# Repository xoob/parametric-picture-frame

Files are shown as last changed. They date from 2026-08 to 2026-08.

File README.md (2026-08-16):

# Parametric Picture Frame

We have a 130 × 90 cm painting on stretched canvas and no frame for it. A real
frame in that size costs a fortune, so I'm printing one — on an A1 Mini with a
180 mm bed. This generator does the math for that: it splits the frame into 38
pieces with press-fit dovetails (no glue), plus 18 clips that hold the canvas
from behind.

Everything is one OpenSCAD project. Pick one of three *Querschnitt* (cross-section) styles, set
your canvas size, and the ornament is generated mathematically so that every
seam lands in a valley of the pattern. The finished frame comes out around
145 × 105 cm with an 85 mm moulding. The painting keeps hanging on its own two
wall screws — the frame just clips onto the stretcher and adds the drama.

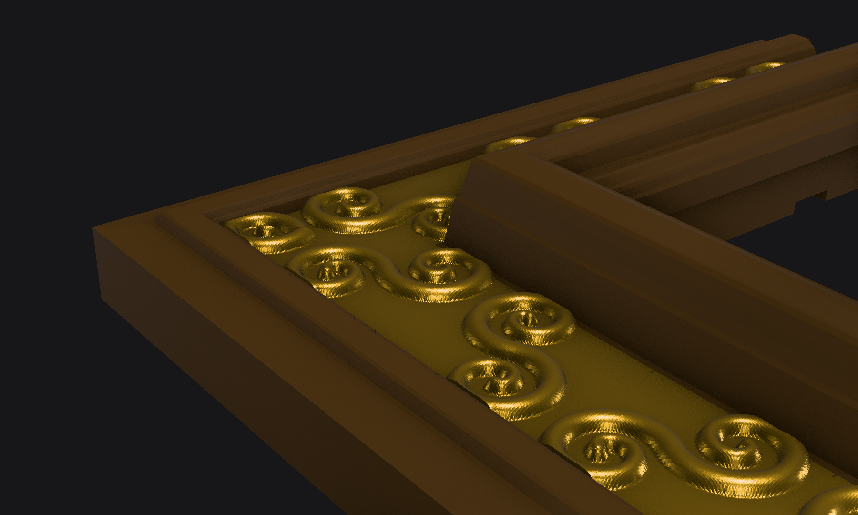
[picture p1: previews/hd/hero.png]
Frame corner, F3D render


| | |
|---|---|
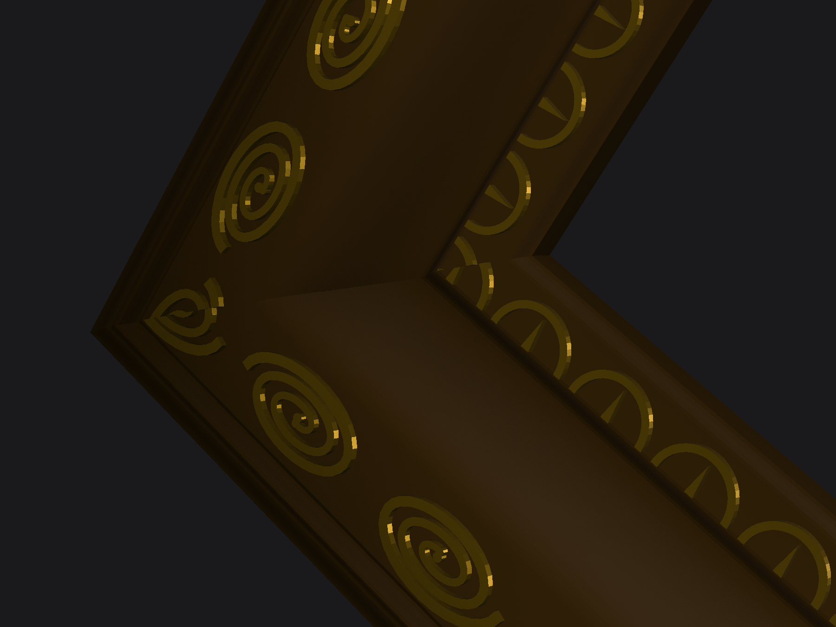
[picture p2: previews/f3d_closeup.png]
Corner close-up, F3D render
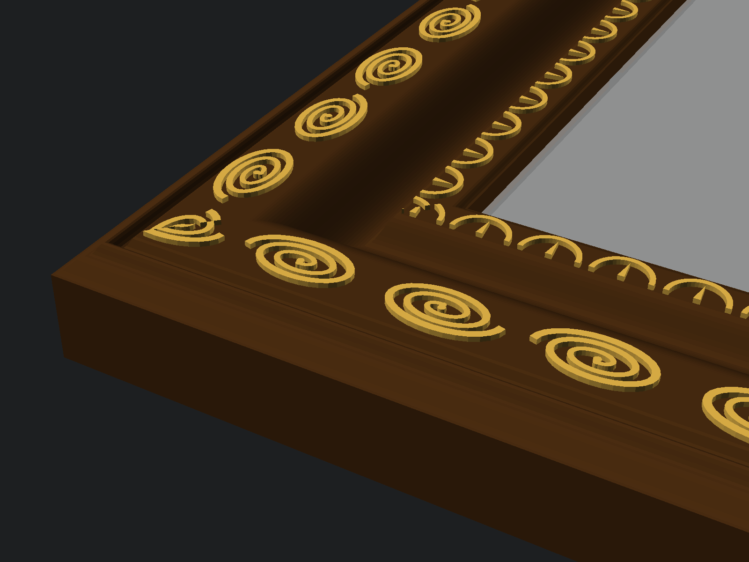
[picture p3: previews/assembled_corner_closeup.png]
Corner detail, OpenSCAD preview
|  |  |
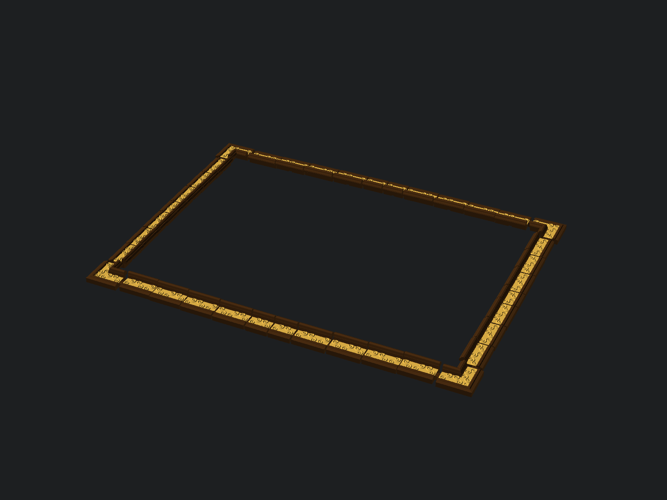
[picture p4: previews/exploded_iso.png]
Exploded segmentation view
|  | View [`parametric-picture-frame.glb`](parametric-picture-frame.glb) interactively at [f3d.app/viewer](https://f3d.app/viewer) |

## Files

- `parametric-picture-frame.scad` — all parameters (OpenSCAD Customizer compatible) + render modes
- `lib/profiles.scad` — the 3 cross-section styles: `ogee`, `reverse_ogee`, `ripple`
- `lib/ornament.scad` — mathematically generated relief (running scroll + scallop bands)
- `lib/segmentation.scad` — bed-aware cut planning + dovetail joints
- `lib/clips.scad` — canvas retainer clips
- `export-all.sh` — exports every part STL into `stl/`

## Bambu Studio export

The project 3mf is built by the local `openscad-3mf` skill (Claude Code), not
by a script in this repo:

```
./export-all.sh
read -r NH NV <<< "$(grep -o 'COUNTS [0-9]* [0-9]*' /tmp/frame_bom.echo | awk '{print $2, $3}')"
parts=(corner_BL B{1..$NH} corner_BR R{1..$NV} corner_TR T{$NH..1} corner_TL L{$NV..1} clips)
python3 ~/.claude/skills/openscad-3mf/scripts/build-3mf.py stl/${^parts}.stl \
  --out parametric-picture-frame.3mf --overrides bambu/overrides.json
```

Result: 39 objects on 23 A1 Mini plates in assembly order (plate previews
render on first slice), presets set (A1 mini 0.6 nozzle, PLA Matte, 0.42mm
Extra Draft) and the overrides from `bambu/overrides.json` — lightning infill,
10%, 2 walls, Arachne, auto supports — bundled as orange modified fields.
Nothing is sliced: open in Bambu Studio, check, slice, print plate by plate.

The 3mf is a Bambu Studio project file — plates and settings are Bambu-specific
metadata. Other slicers: use the STLs from `./export-all.sh` instead.

## Render modes (`render_mode`)

| mode | output |
|---|---|
| `assembled` | whole frame + ghost canvas (sanity view) |
| `exploded` | all parts pulled apart, tenons visible |
| `part` | one printable piece: `part_kind` (`straight`/`corner`) + `part_leg` + `part_index` |
| `fit_test` | small dovetail coupon pair — **print this first** |
| `clips` | plate with all retainer clips |
| `bom` | no geometry; echoes part list, sizes, screw count |

Corners are named by the leg at whose CCW start they sit: `bottom`→BL,
`right`→BR, `top`→TR, `left`→TL. Every part has its ID engraved in the back.

## Print settings (tested target)

- Bambu A1 Mini, Cool Super Tack plate, Matte Black PLA, 0.6 mm nozzle
- Orientation: decorative face UP (exports already lie this way)
- Supports ON (auto): the lip underside floats over the rabbet void — supports
  generate only there. The 3mf overrides enable this
- 2 walls, **lightning infill** — the frame is decorative, not structural
- The dovetail pocket roof is a small internal bridge; default bridge settings are fine

## Workflow

1. **Print `fit_test.stl`** (both coupons). Press together face-down like the
   real parts. Too tight → raise `dovetail_clearance` (steps of 0.04);
   too loose → lower it or raise `dovetail_taper`.
2. **Measure the coupon** (nominal 28 mm blocks). If it printed short, set the
   shrink factor, e.g. 0.3% short → `./export-all.sh 1.003`. The factor scales
   every part identically, so joints stay matched. On a 1300 mm span 0.3%
   is ~4 mm — this matters; `fit_clearance = 4` also budgets for it.
3. **Export everything**: `./export-all.sh [shrink]` → `stl/`.
4. **Print** 38 parts + `clips.stl` (18 clips, ~1 part per A1 Mini plate for
   the big segments).
5. **Assemble face-down on a flat surface**: corners first, then straights,
   dropping each tenon into its neighbor's pocket and pressing until seated.
   IDs run CCW: BL → B1…B7 → BR → R1…R5 → TR → T7…T1 → TL → L5…L1.
   Optional: a drop of CA glue in each pocket for permanence.
6. **Mount**: lay the frame face-down, drop the canvas into the pocket
   (it sits fully recessed), screw the 14 clips into the pilot-hole pockets
   (M3 × 8 self-tapping), noses over the stretcher bars. Rehang the painting
   on its existing two wall screws — the frame rides on the stretcher and the
   flat back sits flush against the wall.

## Key parameters

- `painting_width/height/thickness` — canvas size (default 1300 × 900 × 20 mm)
- `fit_clearance` — slack per side (default 4 mm; hidden by the lip)
- `lip_overlap` — how far the front lip overlaps the painting face (default 10 mm)
- `frame_scale` — moulding size, proportional to the painting diagonal
- `profile_style` — `ogee` (trade name "Swan": roll + sunken gold channel),
  `reverse_ogee` ("Reverse Scoop": crown rising away from the art), `ripple`
  ("Stepped": ribbed *Wellenleiste* (wave moulding))
- `ornament_*` — relief on/off, height, repeat period (seams always land in valleys)
- `printer` — `A1 Mini`, `A1`, `P1 X1`, `H2D` bed presets
- `dovetail_clearance/taper`, `shrinkage_compensation` — joint fit tuning
- `hanger_keyholes` — opt-in keyholes in the top corners for direct wall mounting

Multi-color gold-on-black like the reference: in Bambu Studio, use
*Color Painting → Height Range* to paint everything above the band surfaces
(top ~1.6 mm of the relief) gold.

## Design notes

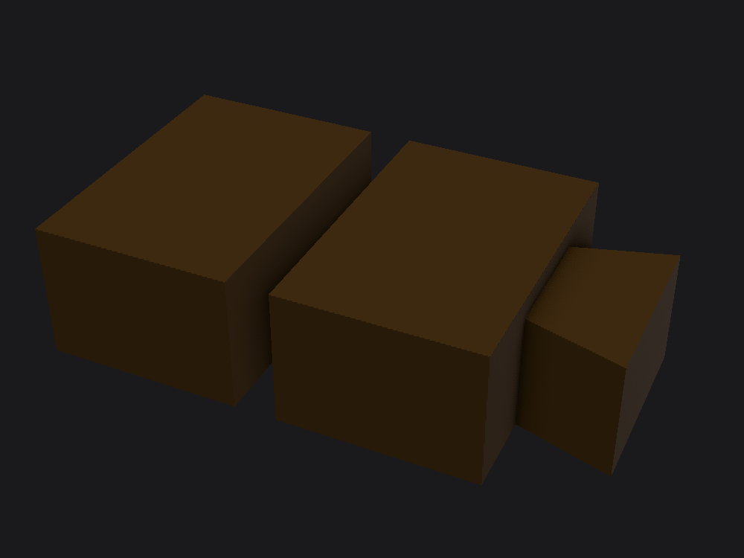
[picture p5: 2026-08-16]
previews/hd/fit_iso.png

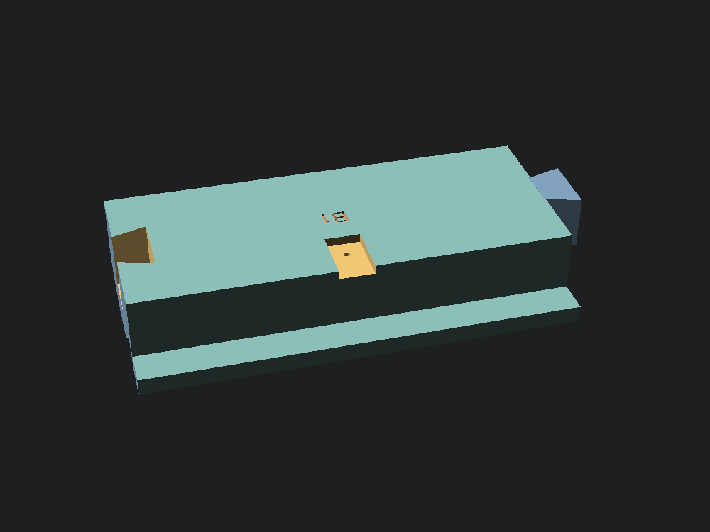
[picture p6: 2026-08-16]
previews/part_b1_back.png

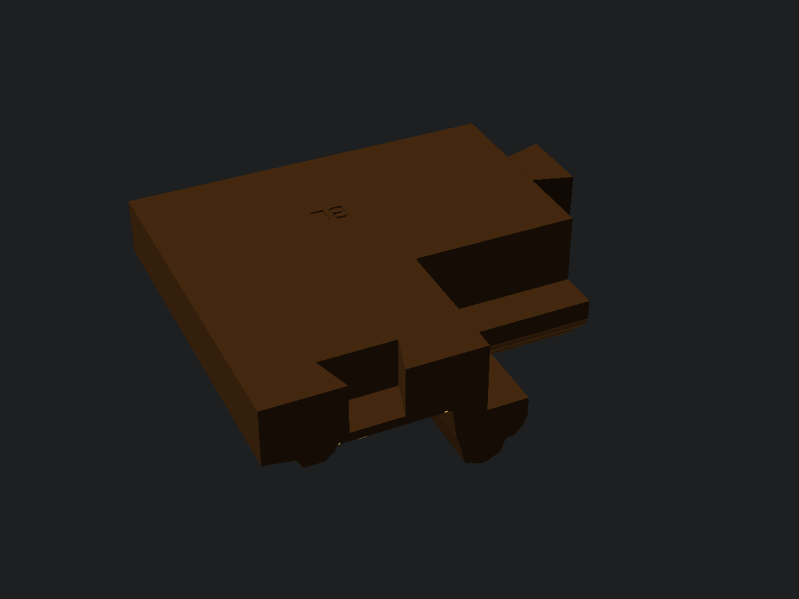
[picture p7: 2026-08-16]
previews/corner_bl_back.png

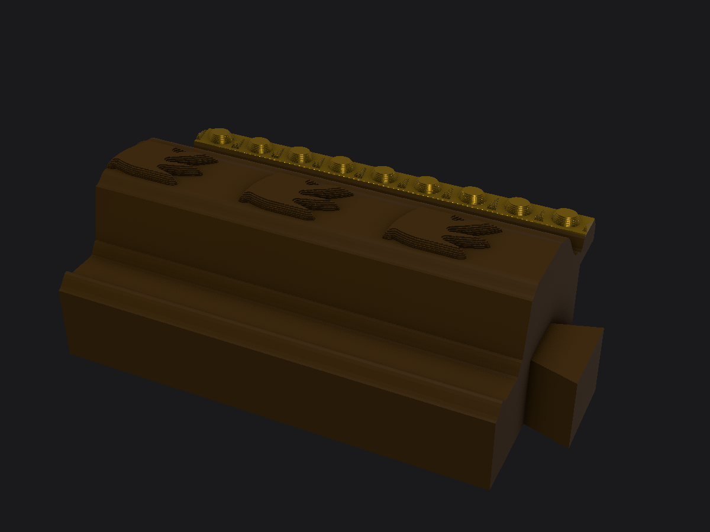
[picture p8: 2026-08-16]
previews/hd/style_revogee.png

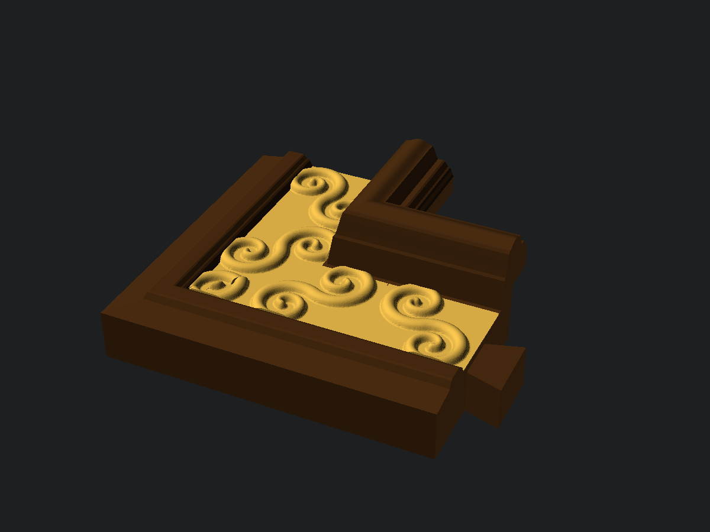
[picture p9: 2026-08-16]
previews/corner_bl_iso.png

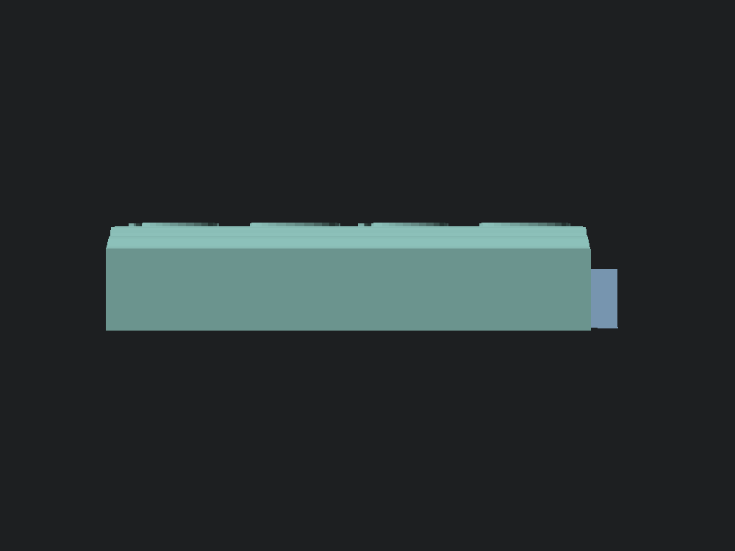
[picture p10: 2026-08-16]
previews/part_b2_front.png

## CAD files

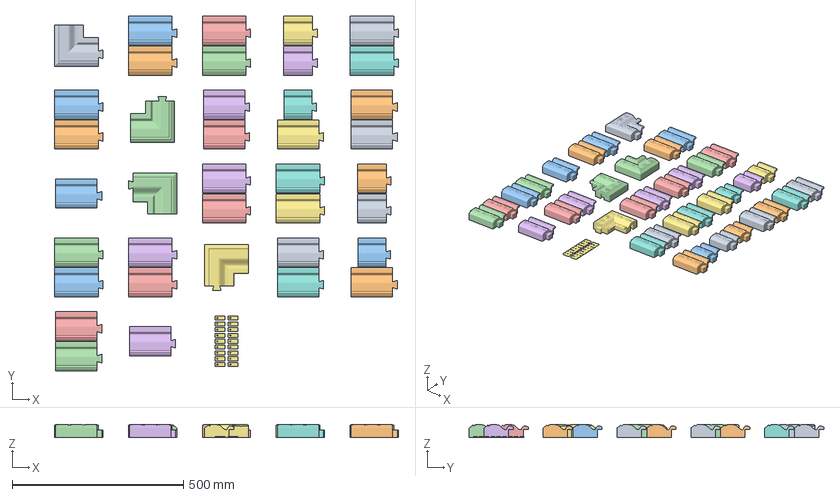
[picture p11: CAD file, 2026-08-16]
parametric-picture-frame.3mf
1005.7 x 1036.8 x 38.9 mm
corner_BL.stl
B1.stl
B2.stl
B3.stl
B4.stl
B5.stl
B6.stl
B7.stl
B8.stl
B9.stl
B10.stl
corner_BR.stl
R1.stl
R2.stl
R3.stl
R4.stl
R5.stl
R6.stl
R7.stl
corner_TR.stl
T10.stl
T9.stl
T8.stl
T7.stl
T6.stl
T5.stl
T4.stl
T3.stl
T2.stl
T1.stl
corner_TL.stl
L7.stl
L6.stl
L5.stl
L4.stl
L3.stl
L2.stl
L1.stl
clips.stl

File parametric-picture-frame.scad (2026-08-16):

// Parametric ornate picture frame, segmented for small-bed 3D printing.
//
// The frame is generated around a frameless canvas painting, split into
// one-piece L corners plus straight segments that each fit the selected
// printer bed, joined by glueless press-fit dovetails. The canvas sits fully
// recessed; printed clips hold it and carry the frame off the stretcher.
//
// Print orientation (all parts): decorative face UP, back plane on the bed.
// Supports required: the lip underside floats over the rabbet void.
// Suggested slicing: 0.6 mm nozzle, 2 walls, lightning infill, auto supports.
//
// Workflow: print fit_test first, tune dovetail_clearance/shrinkage_compensation,
// then export all parts with export-all.sh.

/* [Painting] */
// Painting width (mm)
painting_width = 1300;        // [100:5:3000]
// Painting height (mm)
painting_height = 900;        // [100:5:3000]
// Painting/stretcher thickness (mm)
painting_thickness = 20;      // [5:1:60]
// Slack per side around the canvas (mm) — covers PLA shrinkage over long spans
fit_clearance = 4;            // [0:0.5:10]
// Front lip overlapping the painting face (mm)
lip_overlap = 10;             // [4:1:30]

/* [Frame look] */
// Cross-section style
profile_style = "ogee";       // [ogee, reverse_ogee, ripple]
// Moulding scale, proportional to painting size (1.0 = 5.4% of diagonal)
frame_scale = 1.0;            // [0.5:0.05:2.0]
// Generate relief ornament on the bands
ornament_enable = true;
// Ornament relief height (mm)
ornament_depth = 2.6;         // [1.0:0.2:4]
// Target ornament repeat period (mm)
ornament_period_target = 42;  // [24:2:80]
// Preview color of the frame body (previews only, not exported)
body_color = "#43280f";
// Preview color of the ornament relief (previews only, not exported)
ornament_color = "#d4a843";

/* [Printer / segmentation] */
// Bed preset
printer = "A1 Mini";          // [A1 Mini, A1, P1 X1, H2D]
// Keep-out margin per bed side (mm)
bed_margin = 2.5;             // [0:0.5:10]
// Dovetail clearance per side (mm) — press fit; tune with fit_test
dovetail_clearance = 0.08;    // [0:0.02:0.5]
// Dovetail flank taper (deg) — wedge-locks the glueless joint
dovetail_taper = 0.4;         // [0:0.1:2]
// Uniform XY scale on exported parts (1.003 = +0.3% shrink compensation)
shrinkage_compensation = 1.0; // [0.99:0.001:1.02]

/* [Output] */
render_mode = "assembled";    // [assembled, exploded, part, profile, hero, fit_test, clips, bom]
// Which kind of part to export (render_mode=part)
part_kind = "straight";       // [straight, corner]
// Leg; a corner is the one at this leg's CCW start: bottom=BL, right=BR, top=TR, left=TL
part_leg = "bottom";          // [bottom, right, top, left]
// Straight segment number along the leg (CCW direction)
part_index = 1;               // [1:1:12]
// Gap between parts in exploded view (mm)
explode_gap = 30;             // [0:5:100]
// Restrict assembled output to one material group (for colored GLB/3MF export)
export_group = "all";         // [all, body, ornament]

/* [Mounting] */
// Canvas recess behind the back plane (mm); also the rabbet depth minus canvas
rabbet_extra = 4;             // [2:1:10]
// Keyhole wall hangers in the two top corners (normally the frame hangs on the stretcher)
hanger_keyholes = false;

/* [Hidden] */
$fa = 5;
$fs = 0.5;          // coarsest acceptable for a 0.4 mm nozzle; we print 0.6
curve_step = 0.8;   // profile sampling step (mm)
orn_embed = 0.6;    // how deep ornament sinks into the band surface (mm)
label_depth = 0.8;  // part ID engraving depth in the back (mm)

// ---- derived dimensions (all mm) ----
sight_w = painting_width - 2 * lip_overlap;
sight_h = painting_height - 2 * lip_overlap;
lip_w = lip_overlap + fit_clearance;
face_w = 0.054 * norm([painting_width, painting_height]) * frame_scale;
rabbet_depth = painting_thickness + rabbet_extra;
profile_h = max(prof_h_ratio(profile_style) * face_w, rabbet_depth + 12);
frame_ow = sight_w + 2 * face_w;
frame_oh = sight_h + 2 * face_w;

bed = printer == "A1 Mini" ? [180, 180] :
      printer == "A1"      ? [256, 256] :
      printer == "P1 X1"   ? [256, 256] :
      printer == "H2D"     ? [350, 320] :
      assert(false, str("unknown printer: ", printer)) [0, 0];
usable = min(bed[0], bed[1]) - 2 * bed_margin;

include <lib/profiles.scad>
include <lib/segmentation.scad>
include <lib/ornament.scad>
include <lib/clips.scad>

PC = prof_curve(profile_style);

// dovetail geometry, centered on the solid body between rabbet wall and outer edge
dt_yc = (face_w - lip_w) / 2;
dt_wn = 0.20 * face_w;
dt_wh = 0.30 * face_w;
dt_dl = 0.16 * face_w;
dt_h = min(rabbet_depth - 2,
           profile_h * prof_min_z(PC,
             (face_w - (dt_yc + dt_wh / 2 + 2)) / face_w,
             (face_w - (dt_yc - dt_wh / 2 - 2)) / face_w) - 2.9);
dt_taper_off = tan(dovetail_taper) * dt_h;

// segmentation grids (horizontal legs: bottom/top; vertical legs: left/right).
// Every part carries its male tenon dt_dl beyond the cut — the FULL part
// including the tenon must fit the bed, so the segment budget shrinks by dt_dl.
usable_part = usable - dt_dl;
p_h = grid_period(frame_ow, ornament_period_target);
p_v = grid_period(frame_oh, ornament_period_target);
cuts_h = cuts_for(frame_ow, p_h, usable_part);
cuts_v = cuts_for(frame_oh, p_v, usable_part);
nseg_h = len(cuts_h) - 1;
nseg_v = len(cuts_v) - 1;
arm_h = cuts_h[0];
arm_v = cuts_v[0];

// ---- sanity checks ----
assert(face_w <= usable, "moulding wider than the printer bed — reduce frame_scale");
assert(profile_h * prof_min_z(PC, 0, lip_w / face_w) >= rabbet_depth + 5,
       "lip too thin over the rabbet — raise frame_scale or lower rabbet_extra");
assert(dt_h >= 8, "dovetail too shallow — raise frame_scale");
// bed-fit including the protruding tenon (a part's true bounding box)
assert(max([for (i = [1:nseg_h]) cuts_h[i] - cuts_h[i - 1]]) + dt_dl <= usable,
       "segment + tenon exceeds bed");
assert(max([for (i = [1:nseg_v]) cuts_v[i] - cuts_v[i - 1]]) + dt_dl <= usable,
       "segment + tenon exceeds bed");
assert(max(arm_h, arm_v) + dt_dl <= usable, "corner + tenon exceeds bed");
assert(orn_min_w >= 2.0, "ornament features below printable width");
assert(part_index >= 1, "part_index starts at 1");

// ---- leg helpers ----
LEGS = ["b", "r", "t", "l"];
function prev_leg(leg) = leg == "b" ? "l" : leg == "r" ? "b" : leg == "t" ? "r" : "t";
function leg_letter(leg) = leg == "b" ? "B" : leg == "r" ? "R" : leg == "t" ? "T" : "L";
function corner_code(leg) = leg == "b" ? "BL" : leg == "r" ? "BR" : leg == "t" ? "TR" : "TL";
function leg_horiz(leg) = leg == "b" || leg == "t";
function legL(leg) = leg_horiz(leg) ? frame_ow : frame_oh;
function leg_p(leg) = leg_horiz(leg) ? p_h : p_v;
function leg_cuts(leg) = leg_horiz(leg) ? cuts_h : cuts_v;
function leg_nseg(leg) = leg_horiz(leg) ? nseg_h : nseg_v;
// clips sit at the centers of the odd straight segments (1, 3, 5, ...)
function clip_xs(leg) = let(cs = leg_cuts(leg))
  [for (i = [0:2:len(cs) - 2]) (cs[i] + cs[i + 1]) / 2];
n_clips = 2 * len(clip_xs("b")) + 2 * len(clip_xs("r"));

// leg-local -> global point mapping (matches leg_xform)
function leg_pt(leg, x, y) =
  leg == "b" ? [-frame_ow / 2 + x, -frame_oh / 2 + y] :
  leg == "r" ? [frame_ow / 2 - y, -frame_oh / 2 + x] :
  leg == "t" ? [frame_ow / 2 - x, frame_oh / 2 - y] :
               [-frame_ow / 2 + y, frame_oh / 2 - x];

function corner_center(leg) =
  leg == "b" ? [-frame_ow / 2 + arm_h / 2, -frame_oh / 2 + arm_v / 2] :
  leg == "r" ? [frame_ow / 2 - arm_h / 2, -frame_oh / 2 + arm_v / 2] :
  leg == "t" ? [frame_ow / 2 - arm_h / 2, frame_oh / 2 - arm_v / 2] :
               [-frame_ow / 2 + arm_h / 2, frame_oh / 2 - arm_v / 2];

function _unit2(v) = norm(v) < 1e-9 ? [1, 0] : v / norm(v);

module leg_xform(leg) {
  if (leg == "b") translate([-frame_ow / 2, -frame_oh / 2, 0]) children();
  else if (leg == "r") translate([frame_ow / 2, -frame_oh / 2, 0]) rotate([0, 0, 90]) children();
  else if (leg == "t") translate([frame_ow / 2, frame_oh / 2, 0]) rotate([0, 0, 180]) children();
  else translate([-frame_ow / 2, frame_oh / 2, 0]) rotate([0, 0, 270]) children();
}

// ---- leg geometry (leg-local: runs +X over [0,L], outer edge at y=0) ----
module leg_body(L) {
  rotate([90, 0, 90])
    linear_extrude(L, convexity = 10)
      polygon(leg_xsec_pts(PC, face_w, profile_h, lip_w, rabbet_depth, curve_step));
}

function wedge_pts(L) = [[0, 0], [L, 0], [L - face_w, face_w], [face_w, face_w]];

module leg_wedge(L) {
  linear_extrude(profile_h + ornament_depth + 2, convexity = 10)
    polygon(wedge_pts(L));
}
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

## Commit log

2026-08-16 Parametric segmented picture frame for small-bed 3D printing
    Ornate OpenSCAD frame generated around a frameless canvas painting:
    3 profile styles, mathematically generated relief ornament, printer-aware
    segmentation with glueless press-fit dovetails, canvas retainer clips,
    and a GLB/F3D beauty-render pipeline.
    [parametric-picture-frame.scad]
2026-08-16 add bambu studio project export
    [parametric-picture-frame.3mf]
2026-08-16 fit tenons on the bed, own the 3mf plating, black filament
    The segment budget ignored the protruding tenon, so straight parts were
    184 mm on a 180 mm bed. Segmentation now subtracts dt_dl (38 parts + 18
    clips). The CLI arranger drifts and mispairs, so bambu/fixup-3mf.py takes
    over plating: geometric pairing, centered placement, verified bounds.
    Filament display color was unset (green); now Matte Black. Overrides now
    include the Arachne wall generator.
    [parametric-picture-frame.3mf, parametric-picture-frame.scad]
2026-08-16 enable supports for the floating lip, move 3mf pipeline into openscad-3mf skill
    [parametric-picture-frame.3mf, parametric-picture-frame.scad]
2026-08-16 rebuild profiles from reference massing, add profile+hero render modes, heightmap scroll
    [parametric-picture-frame.scad]
